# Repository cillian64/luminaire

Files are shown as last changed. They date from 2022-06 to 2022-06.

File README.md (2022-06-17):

# Luminaire

A small light intended to hang in my tent for camping.  Powered by a single AA
battery (lifetime should be 10-20 hours depending on battery capacity and
brightness setting).  Uses the handy ZXSC310 from Diodes Inc as a step-up
(boost) converter.

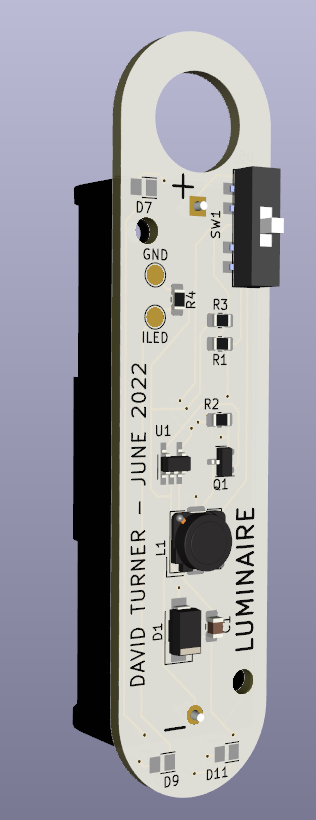
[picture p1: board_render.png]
A 3d render of the PCB


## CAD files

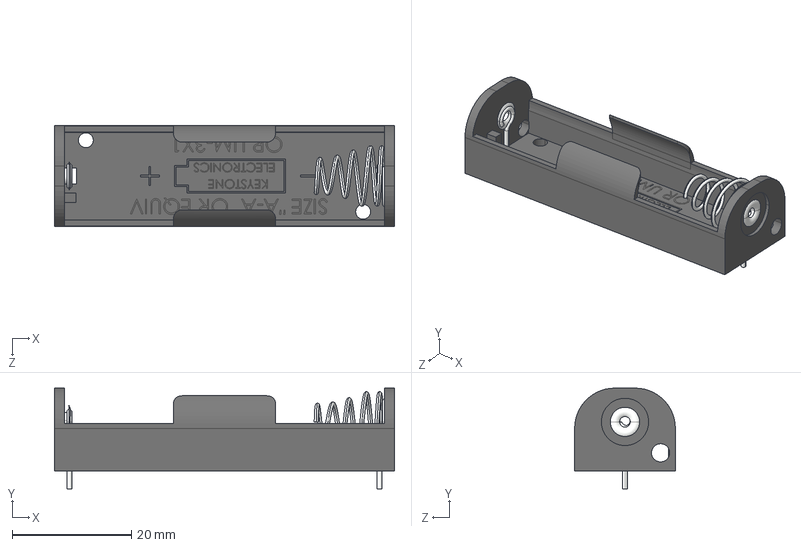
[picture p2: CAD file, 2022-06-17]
luminaire/3d_models/keystone-PN2460.STEP
57.0 x 16.9 x 16.9 mm

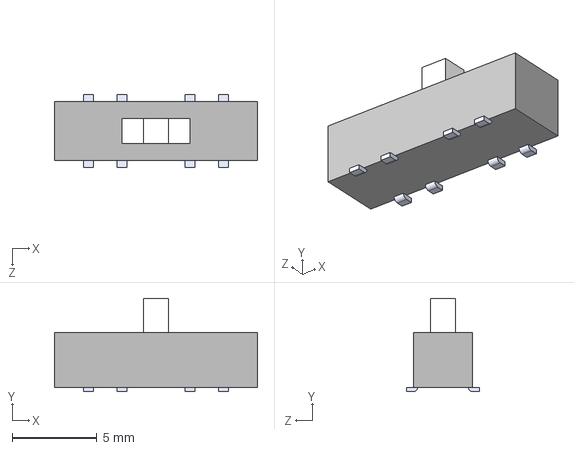
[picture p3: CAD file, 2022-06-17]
luminaire/3d_models/CL-SB-23B-0XX.STEP
12.0 x 5.50 x 4.30 mm

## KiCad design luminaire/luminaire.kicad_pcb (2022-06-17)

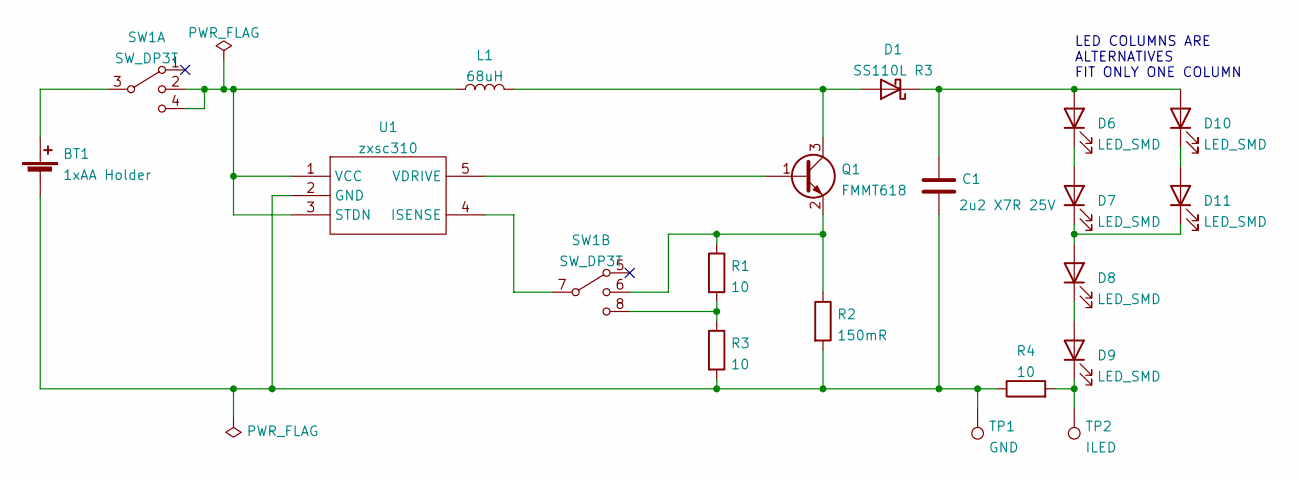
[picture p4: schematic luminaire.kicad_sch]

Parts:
BT1: 1xAA Holder; BatteryHolder_Keystone_2460_1xAA; Farnell 3126558
C1: 2u2 X7R 25V; C_0805_2012Metric_Pad1.18x1.45mm_HandSolder; Farnell 1657931
D1: SS110L R3; D_SMA; Farnell 1559156
D6, D7, D8, D9, D10, D11: LED_SMD; LED_Cree-XQ_HandSoldering; Farnell 1855550
L1: 68uH; L_TDK_SLF6045; Farnell 2917136
Q1: FMMT618; SOT-23; Farnell 9526439
R1, R3, R4: 10; R_0805_2012Metric_Pad1.20x1.40mm_HandSolder; Farnell 2331768
R2: 150mR; R_0805_2012Metric_Pad1.20x1.40mm_HandSolder; Farnell 3790820
SW1: SW_DP3T; CL-SB-23B-0XX; Farnell 2978768
TP1: GND; TestPoint_Pad_D2.0mm
TP2: ILED; TestPoint_Pad_D2.0mm
U1: zxsc310; SOT-23-5_HandSoldering; Farnell 3483179

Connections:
unnamed: BT1.1 (+), SW1.3
unnamed: BT1.2 (-), C1.2, R2.2, R3.2, R4.1, TP1.1, U1.2 (GND)
unnamed: C1.1, D1.1 (K), D6.2 (A), D10.2 (A)
unnamed: D1.2 (A), L1.2, Q1.3 (C)
unnamed: D6.1 (K), D7.2 (A)
unnamed: D8.1 (K), D9.2 (A)
unnamed: D9.1 (K), R4.2, TP2.1
unnamed: D10.1 (K), D11.2 (A)
unnamed: D7.1 (K), D8.2 (A), D11.1 (K)
unnamed: L1.1, SW1.2, SW1.4, U1.1 (VCC), U1.3 (STDN)
unnamed: Q1.1 (B), U1.5 (VDRIVE)
unnamed: Q1.2 (E), R1.1, R2.1, SW1.6
unnamed: R1.2, R3.1, SW1.8
unnamed: SW1.7, U1.4 (ISENSE)

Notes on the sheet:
LED COLUMNS ARE ALTERNATIVES FIT ONLY ONE COLUMN

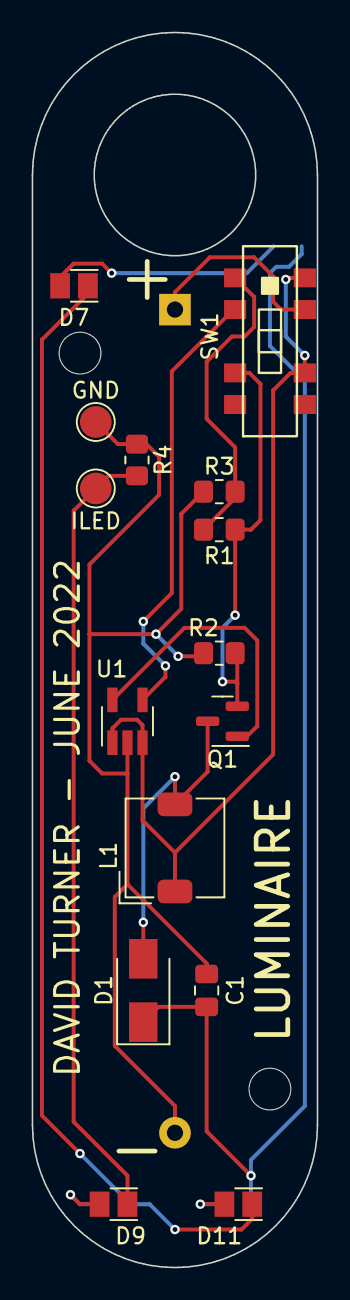
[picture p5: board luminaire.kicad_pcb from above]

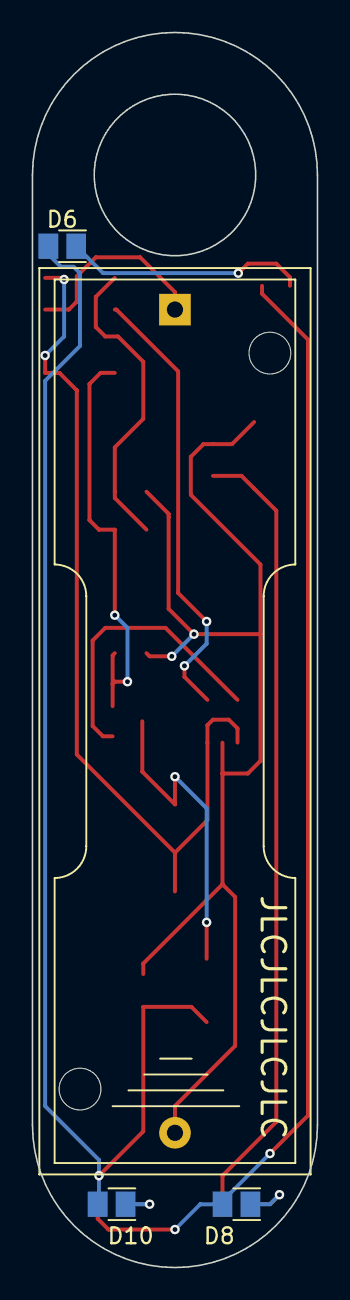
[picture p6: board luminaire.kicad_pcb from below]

Board: 2 copper layers, 18.0 x 78.0 mm, 19 parts (4 on the bottom side), 14 nets.

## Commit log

2022-06-17 First draft with PTH LEDs
    Schematic, PCB placement with PTH LEDs (no routing)
    [CL-SB-23B-0XX.STEP, keystone-PN2460.STEP, luminaire.kicad_pcb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]
2022-06-17 Remove PTH LEDs
    They are kinda massive, make layout awkward, and have really narrow
    viewing angles.
    [luminaire.kicad_pcb, luminaire.kicad_sch]
2022-06-17 Finalise design
    [luminaire.kicad_pcb, luminaire.kicad_sch]
2022-06-17 Finalise BOM and gerbers
    [luminaire-B_Cu.gbl, luminaire-B_Mask.gbs, luminaire-B_Silkscreen.gbo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]
2022-06-17 Trim pins on battery holder 3d model
    [keystone-PN2460.STEP]
2022-07-15 Annotate schematic with measured currents
    [luminaire.kicad_sch]
